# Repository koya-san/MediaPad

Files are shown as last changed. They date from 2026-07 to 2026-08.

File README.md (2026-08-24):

# MediaPad
I am making a macropad under Hack Club. My goal with this macropad is to allow for dedicated macros for streaming and editing alongside a screen that states which OBS I am on.
The macropad is a 3x3 that used MX-style switches and a 128x32 OLED screen. Side note, some files are named StreamerPad, the old name I gave for this project that I would sometimes mix up with MediaPad :P

MediaPad


Schematic


PCB


Case


My case will case will come together with 4 screws.
BOM: Seeed XIAO RP2040, 9x 1N4148 Diodes, 9x MX-Style switches, 1x 0.91 inch OLED display, 9x white blank DSA keycaps, 4x M3x16mm screws, 4x M3x5mx4mm heatset inserts

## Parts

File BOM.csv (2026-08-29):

Part | Quantity | Cost (Total) | Link | Selection
Seeed XIAO RP2040 | 1 | $3.99 | https://www.seeedstudio.com/XIAO-RP2040-v1-0-p-5026.html
1N4148 Diodes | 10 | $1.56 | https://www.digikey.com/en/products/detail/vishay-general-semiconductor-diodes-division/1N4148-TAP/3104053
KTT Silent Blue Switch | 10 | $0.99 | https://www.aliexpress.us/item/3256810434236860.html | 10 PCS
1 x 0.91 inch OLED Graphic 128x32 - I2C (White) | 1 | $3.90 | https://www.displaymodule.com/products/0-91-inch-oled-graphic-display-128x32-with-i2c | White
Black Translucent DSA Keycaps | 50 | $0.99 | https://www.aliexpress.us/item/3256808640925468.html | 50pcs LBlack
M3x16mm hex screws | 50 | $0.99 | https://www.aliexpress.us/item/3256808898544302.html | M3 x 50Pieces + 16mm
M3x5mx4mm heatset inserts | 4 | $0.99 | https://www.aliexpress.us/item/2255800046543591.html | M3 X D5.0 X L4.0
Case 3D Print (Bottom) | 1 |  | https://printlegion.hackclub.com/
Case 3D Print (Middle) | 1 |  | https://printlegion.hackclub.com/
Case 3D Print (Top) | 1 |  | https://printlegion.hackclub.com/
PCB | 1 | $11.14 | https://jlcpcb.com/ | JLCPCB

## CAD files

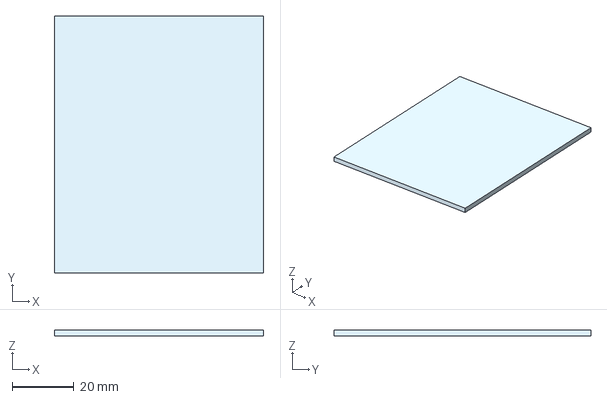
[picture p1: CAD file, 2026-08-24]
CAD/PCB_BLOCK.step
67.5 x 82.8 x 2.00 mm

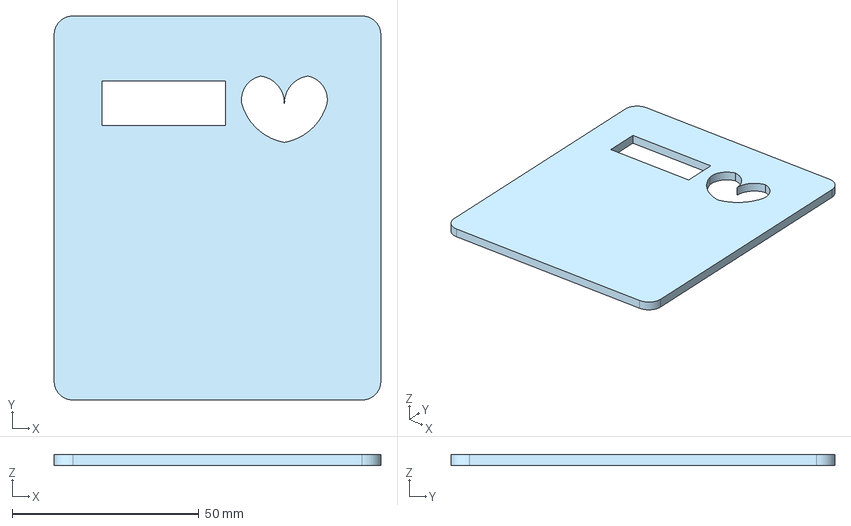
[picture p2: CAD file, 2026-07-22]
Production/BOTTOM_StreamerPad.step
87.5 x 102.8 x 3.00 mm

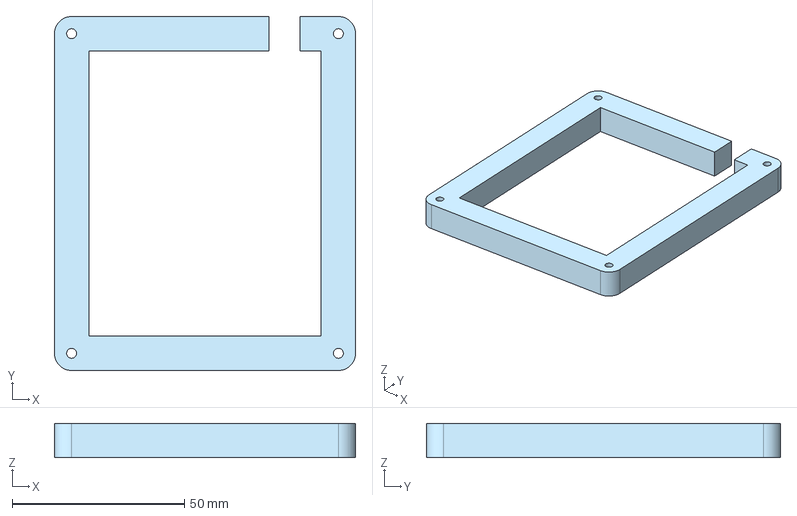
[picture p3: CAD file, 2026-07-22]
Production/MIDDLE_StreamerPad.step
87.5 x 102.8 x 10.0 mm

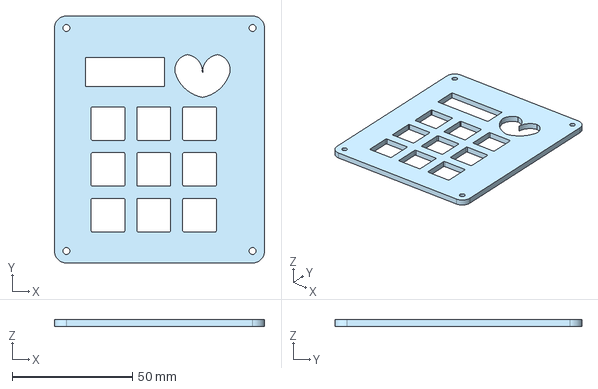
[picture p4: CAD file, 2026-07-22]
Production/TOP_StreamerPad.step
87.5 x 102.8 x 3.00 mm

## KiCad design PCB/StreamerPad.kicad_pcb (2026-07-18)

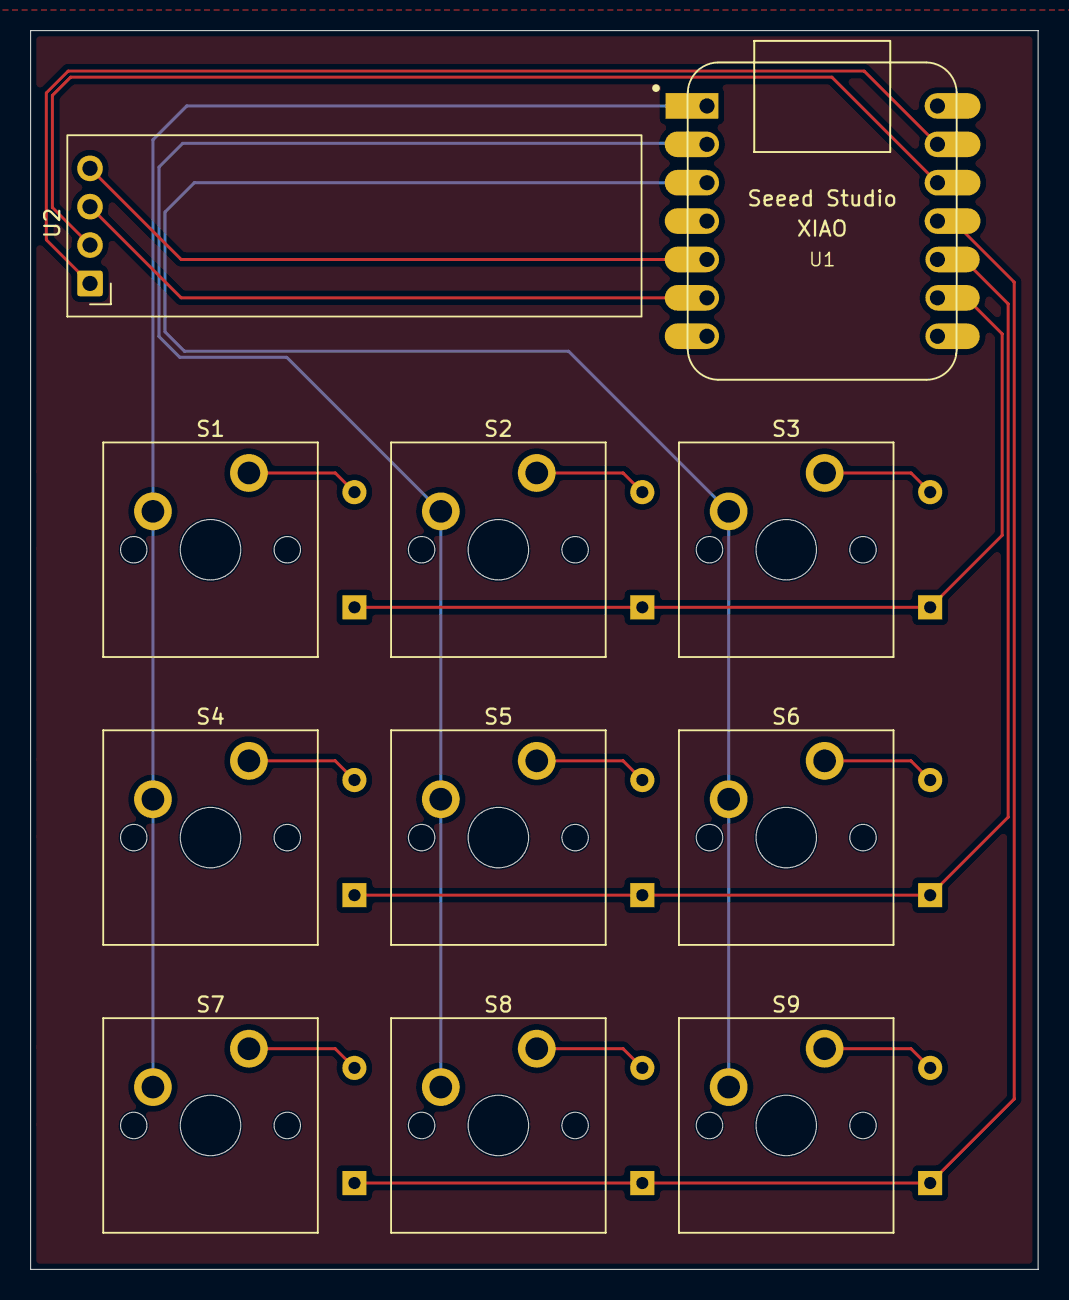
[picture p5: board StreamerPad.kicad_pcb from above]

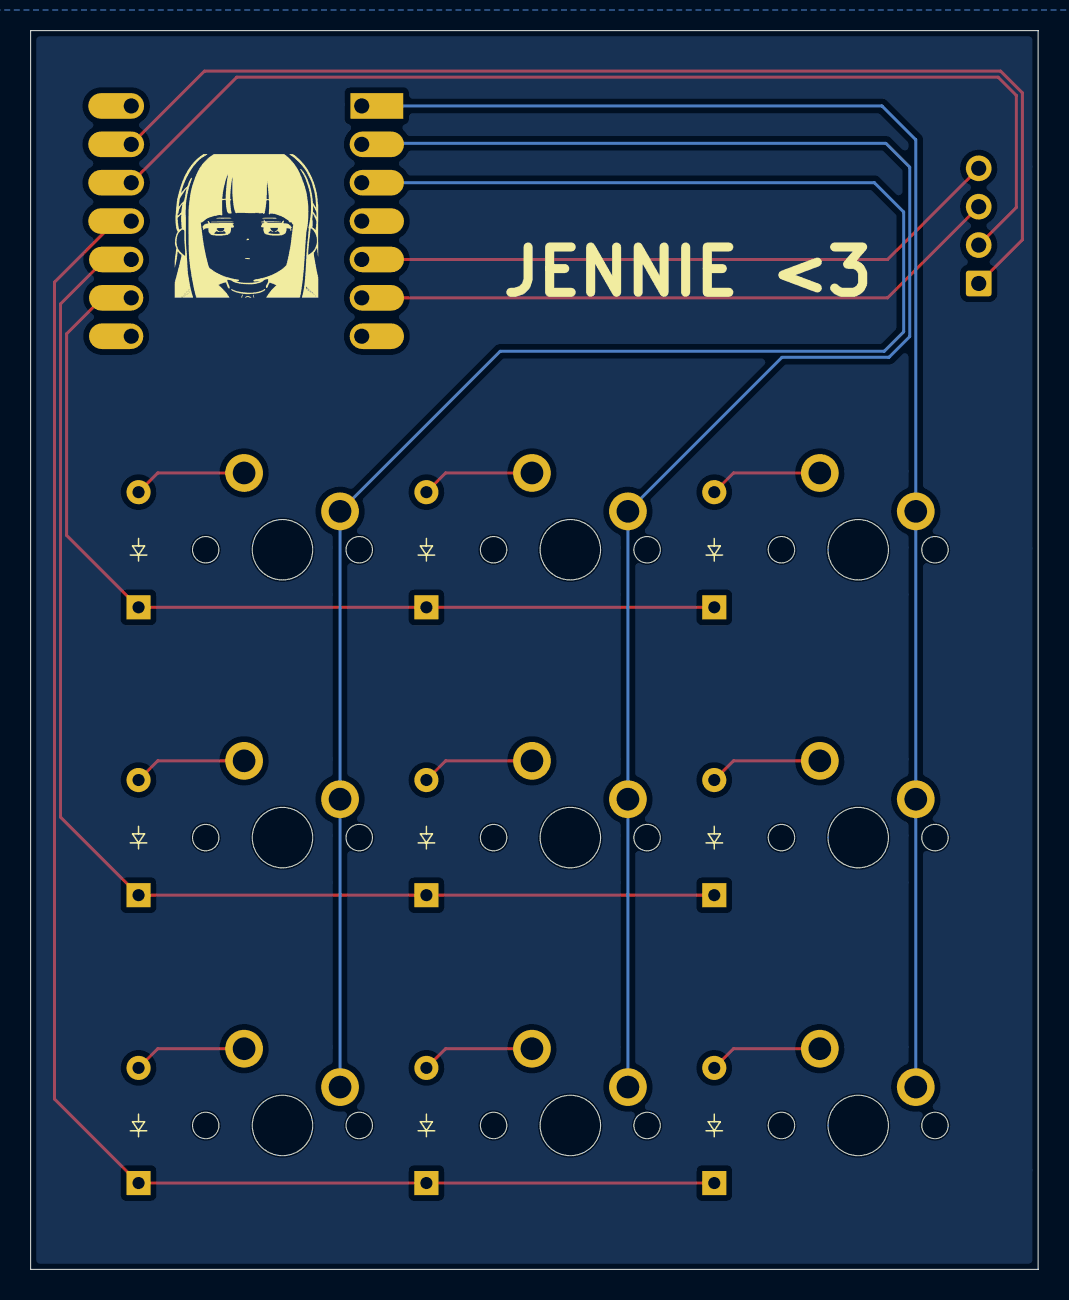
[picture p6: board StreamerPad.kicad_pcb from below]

Board: 2 copper layers, 66.7 x 82.0 mm, 20 parts (9 on the bottom side), 19 nets.

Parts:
D1, D2, D3, D4, D5, D6, D7, D8, D9: Diode_DO-35
S1, S2, S3, S4, S5, S6, S7, S8, S9: MX_PCB_1.00u
U1: MOUDLE-SEEEDUINO-XIAO; XIAO-Generic-Hybrid-14P-2.54-21X17.8MM
U2: ER_OLEDM0.91_1x-I2C

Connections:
Column 0: S1.1, S4.1, S7.1, U1.1 (PA02_A0_D0)
Column 1: S2.1, S5.1, S8.1, U1.2 (PA4_A1_D1)
Column 2: S3.1, S6.1, S9.1, U1.3 (PA10_A2_D2)
GND: U1.13 (GND), U2.1 (GND)
unnamed: D1.2 (A), S1.2
unnamed: D2.2 (A), S2.2
unnamed: D3.2 (A), S3.2
unnamed: D4.2 (A), S4.2
unnamed: D5.2 (A), S5.2
unnamed: D6.2 (A), S6.2
unnamed: D7.2 (A), S7.2
unnamed: D8.2 (A), S8.2
unnamed: D9.2 (A), S9.2
Row 0: D1.1 (K), D2.1 (K), D3.1 (K), U1.9 (PA7_A8_D8_SCK)
Row 1: D4.1 (K), D5.1 (K), D6.1 (K), U1.10 (PA5_A9_D9_MISO)
Row 2: D7.1 (K), D8.1 (K), D9.1 (K), U1.11 (PA6_A10_D10_MOSI)
SCL: U1.6 (PA9_A5_D5_SCL), U2.3 (SCL)
SDA: U1.5 (PA8_A4_D4_SDA), U2.4 (SDA)
VCC: U1.12 (3V3), U2.2 (VCC)

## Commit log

2026-07-18 Schematic and PCB files from DAY05
    [StreamerPad.kicad_pcb, StreamerPad.kicad_sch]
2026-07-18 DAY05 PCB and Schematic (ver. 2)
    [StreamerPad.kicad_pcb]
2026-07-22 Case .step Files
    [BOTTOM_StreamerPad.step, MIDDLE_StreamerPad.step, TOP_StreamerPad.step]
2026-08-24 Schematic + PCB Files from DAY07
2026-08-24 PCB "block" for the CAD model
    [PCB_BLOCK.step]
2026-08-24 create CAD folder
2026-08-24 Create PCB Folder
2026-08-24 add PCB files
    [StreamerPad.kicad_pcb, StreamerPad.kicad_sch]
2026-08-24 add production files
    [BOTTOM_StreamerPad.step, MIDDLE_StreamerPad.step, TOP_StreamerPad.step]
2026-08-24 Create BOM
    [BOM.csv]
2026-09-14 add PCB project file
2026-10-18 Create STL
2026-10-18 Add .stl versions
2026-10-22 added holes for the screws
2026-10-22 add 5.2mm hole versions
